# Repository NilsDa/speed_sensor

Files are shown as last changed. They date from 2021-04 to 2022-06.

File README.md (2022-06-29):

# Speed_Sensor

This Repository contains the complete KiCad project of the speed_sensor PCB design as well as important Datasheets and lots of random files and data relating to the project.

## important directories

- **/Datasheets** -> self explanatory
- **/KiCad** -> complete KiCad project and resulting gerber files for pcb printing.
- /Software -> miscellaneous software created mainly to experiment with certain things. not critical
- rest: unsorted files and folders containing parts-lists/footprints/... (need to be properly sorted)

## possibilities for simplifying the design

- maybe ditch the rechargeable lithium battery and use a small coin battery (CR2032) instead... majorly simplifies the PCB design and reduces friction points... But, rechargeable would be nice... Just something to think about.

## LICENSE

No license because project is properly unfinished :D Whoever would want access, needs to contact me.

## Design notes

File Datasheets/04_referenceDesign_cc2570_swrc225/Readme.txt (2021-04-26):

XXXXXXXXXXXXXXXXXXXXXXXXXXXXXXXXXXXXXXXXXXXXXXXXXXXXXXXXXXXXXXXX
X   	Artwork and documentation done by: 					X
X									X
X	TEXAS INSTRUMENTS NORWAY LPW              				X
X  									X
X	Address: Gaustadalléen 21    0349 OSLO                                       		X
X	Phone  : (+47) 22 95 85 44   Fax :  (+47) 22 95 89 05                   		X
X   	web: www.ti.com/lpw                            	 			X
X                                                                           	 			X
XXXXXXXXXXXXXXXXXXXXXXXXXXXXXXXXXXXXXXXXXXXXXXXXXXXXXXXXXXXXXXXX

PCB NAME : CC257X EM discrete	
REVISION: 1.0
DATE: 2010-11-12

PCB DESCRIPTION:4 LAYER PCB 1.6 MM
      Copper        1   35 um
      Dielectric  1-2   0.35 mm (e.g. 2x Prepreg 7628 AT05 47% Resin)
      Copper        2   18 um
      Dielectric  2-3   0.76 mm (4 x 7628M 43% Resin)
      Copper        3   18 um
      Dielectric  3-4   0.35 mm (e.g. 2x Prepreg 7628 AT05 47% Resin)
      Copper        4   35 um

  DE104iML or equivalent substrate (Resin contents around 45%, which gives Er=4.42@2.4GHz, TanD=0.016)
  Dimensions in mil (0.001 inch)
  DOUBLE SIDE SOLDER MASK,
  DOUBLE SIDE SILKSCREEN,
  8 MIL MIN TRACE WIDTH AND 8 MIL MIN ISOLATION.
	
ASSEMBLY: 	LABEL CARD WITH "CC257X_EM_D_R1.0"

FILE: CC257X_EM_Discrete_Reference_Design.ZIP PACKED WITH WinZIP containing 
                 
FILE NAME            				DESCRIPTION                               			FILE TYPE

PCB MANUFACTURING FILES:
L1.SPL               				LAYER 1 COMPONENT SIDE/POSITIVE            		EXT. GERBER
L2.SPL	              			LAYER 2 POSITIVE               		                            EXT. GERBER
L3.SPL               				LAYER 3 POSITIVE            		                            EXT. GERBER
L4.SPL	              			LAYER 4 SOLDER SIDE/POSITIVE               		EXT. GERBER
STOPCOMP.SPL         			SOLDER MASK COMPONENT SIDE/NEGATIVE             	EXT. GERBER
STOPSOLD.SPL         			SOLDER MASK SOLDER SIDE/NEGATIVE                	EXT. GERBER
SILKCOMP.SPL         			SILKSCREEN COMPONENT SIDE/POSITIVE            	EXT. GERBER
SILKSOLD.SPL				SILKSCREEN SOLDER SIDE/POSITIVE			EXT. GERBER
GERBER.REP				DRILL and NC DRILL REPORT				ASCII
DRILL.SPL	            			DRILL/MECHANICAL DRAWING                  		EXT. GERBER
NCDRILL.SPL				NC DRILL THROUGH HOLE                     		EXCELLON			
EXT_GERBER.USR	     			PCB PHOTOPLOTTER DEFINITION FILE			ASCII
CNC.USR		     			NC DRILL DEVICE FILE				ASCII

PCB ASSEMBLY FILES:
CC257X_EM_DISCRETE_PARTLIST.XLS		PART LIST					ASCII
PNP_COMP.REP			              PICK AND PLACE COORDINATES, COMPONENT SIDE	ASCII
PNP_SOLD.REP			              PICK AND PLACE COORDINATES, SOLDER SIDE		ASCII
PASTCOMP.SPL         			SOLDER PASTE COMPONENT SIDE               		EXT. GERBER
PASTSOLD.SPL				SOLDER PASTE SOLDER SIDE			EXT. GERBER
ASSYCOMP.SPL        			ASSEMBLY DRAWING COMPONENT SIDE           		EXT. GERBER
ASSYSOLD.SPL				ASSEMBLY DRAWING SOLDER SIDE			EXT. GERBER

PDF FILES:
CC257X_EM_DISCRETE_SCHEMATIC.PDF	CIRCUIT DIAGRAM
CC257X_EM_DISCRETE_LAYOUT.PDF		LAYOUT DIAGRAM

CADSTAR FILES:
CC257X_EM_DISCRETE.SCM			CADSTAR SCHEMATIC FILE
CC257X_EM_DISCRETE.PCB			CADSTAR LAYOUT FILE

README.TXT           			THIS FILE                                 			ASCII

END.

Release history
--------------------------------------------------------------------------------------------------------------
1.0.0 : Initial release.

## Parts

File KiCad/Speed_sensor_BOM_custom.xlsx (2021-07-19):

Source: | C:\Users\nils_\OneDrive\Documents\Projekte\Speed_sensor\speed_sensor\KiCad\Speed_sensor.sch
Date: | 2021-05-12 22:10
Tool: | Eeschema (5.1.9)-1
Component Count: | 61
Ref | Value | Footprint | Bestückung | Datasheet | Comment | LCSC part no. | hat Manu
AE1 | 2450AT18D0100E_right | myparts:2450AT18D0100E |  | ~ |  |  | ja
C1 | 1u | Capacitor_SMD:C_0603_1608Metric_Pad1.08x0.95mm_HandSolder | 16 | ~ |  | C1592 | nein
C2 | 1u | Capacitor_SMD:C_0603_1608Metric_Pad1.08x0.95mm_HandSolder | 16 | ~ |  | C1592 | nein
C3 | 100n | Capacitor_SMD:C_0402_1005Metric_Pad0.74x0.62mm_HandSolder | 2 | ~ |  | C392963 | ja, aber trotzdem bestellen
C4 | 10u | Capacitor_SMD:C_0603_1608Metric_Pad1.08x0.95mm_HandSolder | 17 | ~ |  | C319196 | nein
C5 | 100n | Capacitor_SMD:C_0402_1005Metric_Pad0.74x0.62mm_HandSolder | 2 | ~ |  | C392963 | ja, aber trotzdem bestellen
C6 | 10u | Capacitor_SMD:C_0603_1608Metric_Pad1.08x0.95mm_HandSolder | 17 | ~ |  | C319196 | nein
C7 | 10u | Capacitor_SMD:C_0603_1608Metric_Pad1.08x0.95mm_HandSolder | 17 | ~ |  | C319196 | nein
C8 | 4.7u | Capacitor_SMD:C_0603_1608Metric_Pad1.08x0.95mm_HandSolder | 18 | ~ |  | C19666 | nein
C9 | 100n | Capacitor_SMD:C_0402_1005Metric_Pad0.74x0.62mm_HandSolder | 2 | ~ |  | C392963 | ja, aber trotzdem bestellen
C10 | 100n | Capacitor_SMD:C_0402_1005Metric_Pad0.74x0.62mm_HandSolder | 2 | ~ |  | C392963 | ja, aber trotzdem bestellen
C11 | 100p | Capacitor_SMD:C_0402_1005Metric_Pad0.74x0.62mm_HandSolder | 3 | ~ |  | C696853 | ja
C12 | N.C. | Capacitor_SMD:C_0402_1005Metric_Pad0.74x0.62mm_HandSolder |  | ~ |  |  | -
C13 | 100n | Capacitor_SMD:C_0402_1005Metric_Pad0.74x0.62mm_HandSolder | 2 | ~ |  | C392963 | ja, aber trotzdem bestellen
C14 | 1u | Capacitor_SMD:C_0603_1608Metric_Pad1.08x0.95mm_HandSolder | 16 | ~ |  | C1592 | nein
C15 | 12p | Capacitor_SMD:C_0402_1005Metric_Pad0.74x0.62mm_HandSolder | 1 | ~ |  | C26406 | nein
C16 | 12p | Capacitor_SMD:C_0402_1005Metric_Pad0.74x0.62mm_HandSolder | 1 | ~ |  | C26406 | nein
C17 | 0,8p | Capacitor_SMD:C_0402_1005Metric_Pad0.74x0.62mm_HandSolder | 4 | ~ |  | C40459 | ja
C18 | 8p | Capacitor_SMD:C_0402_1005Metric_Pad0.74x0.62mm_HandSolder | 5 | ~ |  | C258500 | nein
C19 | 8p | Capacitor_SMD:C_0402_1005Metric_Pad0.74x0.62mm_HandSolder | 5 | ~ |  | C258500 | nein
C20 | 100n | Capacitor_SMD:C_0402_1005Metric_Pad0.74x0.62mm_HandSolder | 2 | ~ |  | C392963 | ja, aber trotzdem bestellen
C21 | 10u | Capacitor_SMD:C_0603_1608Metric_Pad1.08x0.95mm_HandSolder | 17 | ~ |  | C319196 | nein
C22 | N.C. | Capacitor_SMD:C_0402_1005Metric_Pad0.74x0.62mm_HandSolder |  | ~ |  |  | -
D1 | Green (3V) | Diode_SMD:D_0603_1608Metric_Pad1.05x0.95mm_HandSolder |  | ~ |  | C205443 | ja
D2 | IN-GREEN | Diode_SMD:D_0603_1608Metric_Pad1.05x0.95mm_HandSolder |  | ~ |  | C205443 | ja
D3 | charging-ORANGE | Diode_SMD:D_0603_1608Metric_Pad1.05x0.95mm_HandSolder |  | ~ |  | C205445 | ja
D4 | DDZ9678 | Diode_SMD:D_SOD-123 |  | ~ |  | C150464 | ja
D5 | Orange-3V | Diode_SMD:D_0603_1608Metric_Pad1.05x0.95mm_HandSolder |  | ~ |  | C205445 | ja
H1 | VOUT | TestPoint:TestPoint_Pad_D1.5mm |  | ~ |  |  | -
H3 | PGOOD | TestPoint:TestPoint_Pad_D1.5mm |  | ~ |  |  | -
H6 | AIN1 | TestPoint:TestPoint_Pad_D1.5mm |  | ~ |  |  | -
H7 | AIN2 | TestPoint:TestPoint_Pad_D1.5mm |  | ~ |  |  | -
H8 | AIN3 | TestPoint:TestPoint_Pad_D1.5mm |  | ~ |  |  | -
H17 | LiPo+ | TestPoint:TestPoint_Plated_Hole_D2.0mm |  | ~ |  |  | -
H18 | LiPo- | TestPoint:TestPoint_Plated_Hole_D2.0mm |  | ~ |  |  | -
J1 | USB_C_Receptacle_USB2.0 | myparts:USB_C_Receptacle_Palconn_UTC16-G_breitePins |  | https://www.usb.org/sites/default/files/documents/usb_type-c.zip |  | C165948 | nein
J2 | SWD | Connector_PinHeader_1.27mm:PinHeader_2x05_P1.27mm_Vertical_SMD |  | ~
L1 | 2,2u | Inductor_SMD:L_0805_2012Metric_Pad1.15x1.40mm_HandSolder | 22 | ~ |  | C95973 | nein
L2 | 15n | Inductor_SMD:L_0402_1005Metric_Pad0.77x0.64mm_HandSolder | 6 | ~ |  | C329619 | nein
L3 | 10u | Inductor_SMD:L_0603_1608Metric_Pad1.05x0.95mm_HandSolder | 19 | ~ |  | C1035 | nein
L4 | 3,9n | Inductor_SMD:L_0402_1005Metric_Pad0.77x0.64mm_HandSolder | 7 | ~ |  | C90196 | ja
R1 | 470 | Resistor_SMD:R_0402_1005Metric_Pad0.72x0.64mm_HandSolder | 8 | ~ | verwende 510 | C25170 | ja
R2 | 10,8k | Resistor_SMD:R_0603_1608Metric_Pad0.98x0.95mm_HandSolder | 20 | ~ | verwende 10,7k | C22857 | nein
R3 | 10k | Resistor_SMD:R_0603_1608Metric_Pad0.98x0.95mm_HandSolder | 21 | ~ |  | C305012 | ja (nur 20)
R4 | 270 | Resistor_SMD:R_0402_1005Metric_Pad0.72x0.64mm_HandSolder | 9 | ~ |  | C310256 | ja
R5 | 270 | Resistor_SMD:R_0402_1005Metric_Pad0.72x0.64mm_HandSolder | 9 | ~ |  | C310256 | ja
R6 | 27k | Resistor_SMD:R_0402_1005Metric_Pad0.72x0.64mm_HandSolder | 10 | ~ |  | C304599 | ja
R7 | 10k | Resistor_SMD:R_0402_1005Metric_Pad0.72x0.64mm_HandSolder | 11 | ~ |  | C140214 | ja
R8 | 12k | Resistor_SMD:R_0402_1005Metric_Pad0.72x0.64mm_HandSolder | 12 | ~ |  | C25535 | ja
R9 | 470k | Resistor_SMD:R_0402_1005Metric_Pad0.72x0.64mm_HandSolder | 13 | ~ |  | C294637 | ja
R10 | 0 | Resistor_SMD:R_0402_1005Metric_Pad0.72x0.64mm_HandSolder | 14 | ~ |  | C60485 | ja
R11 | 270 | Resistor_SMD:R_0402_1005Metric_Pad0.72x0.64mm_HandSolder | 9 | ~ |  | C310256 | ja
R12 | 1M | Resistor_SMD:R_0402_1005Metric_Pad0.72x0.64mm_HandSolder | 15 | ~ |  | C26087 | ja
U1 | BQ24040DSQR | Package_WSON-10:BQ24040DSQR_breitePins |  |  |  | C81080 | ja
U2 | LMV321 | Package_TO_SOT_SMD:SOT-23-5_HandSoldering |  | http://www.ti.com/lit/ds/symlink/lmv324.pdf |  |  | ja
U3 | ST1PS02 | Package_TQFN-12:ST1PS02CQTR_breitePins |  |  | Free Sample (5x) |  | nein
U4 | nRF52832-QFxx | myparts:QFN-48-1EP_6x6mm_P0.4mm_EP4.6x4.6mm_Handsolder |  | http://infocenter.nordicsemi.com/pdf/nRF52832_PS_v1.4.pdf |  |  | ja
U5 | LIS2DH12 | myparts:LGA-12_2x2mm_P0.5mm_Handsolder |  |  |  | C110926 | ja
U6 | TP1941U | Package_TO_SOT_SMD:SOT-353_SC-70-5_Handsoldering |  |  |  | C248711 | ja
Y1 | 32,768kHz | Crystal:Crystal_SMD_G8-2Pin_3.2x1.5mm |  | ~ |  |  | ja
Y2 | 32MHz | myparts:SMD-2016_4P |  | ~ |  |  | ja

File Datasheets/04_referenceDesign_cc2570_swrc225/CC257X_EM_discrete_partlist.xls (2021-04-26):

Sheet: Partlist TI LPW
CC257X EM discrete 1.0
Mark assembled PCB "CC257X_EM_D_R1.0"
Use with PCB rev 1.0
Ref. | Part name | Pcs/unit | Description | Manufacturer | Part number | Supplier | Ordering code | Alt. Manufacturer | Alt. Part number | Alt. Supplier | Alt. Ordering code | Comments
U1 | CC257X | 1 | 1 Channel or 8 Channel ANT RF Network Processor | TI | CC257x | TI | CC257x
C101;C211;C241;C271;C311 | C_100N_0402_X5R_K_10 | 5 | Capacitor, 100n, 0402, X5R, 10%, 10V | Murata | GRM155R71A104KA01D
C221;C231 | C_12P_0402_NP0_J_50 | 2 | Capacitor, 12p, 0402, NP0, 5%, 50V | Murata | GRM1555C1H120JA01D
C321;C331 | C_15P_0402_NP0_J_50 | 2 | Capacitor, 15p, 0402, NP0, 5%, 50V | Murata | GRM1555C1H150JA01D
C251;C261 | C_18P_0402_NP0_J_50 | 2 | Capacitor, 18p, 0402, NP0, 5% 25V | Murata | GRM1555C1H180JZ01D | ELFA | 65-881-23
C201 | C_1N_0402_NP0_J_50 | 1 | Capacitor, 1n, 0402, NP0, 5%, 50V | Murata | GRM1555C1H102JA01D
C252-253;C262 | C_1P0_0402_NP0_C_50 | 3 | Capacitor, 1p, 0402, NP0, +/-0.25pF 50V | Murata | GRM1555C1H1R0CZ01D
C391;C401 | C_1U_0402_X5R_K_6P3 | 2 | Capacitor, 1u, 0402, X5R, 10%, 6.3V | Murata | GRM155R60J105KE19D
C272 | C_220P_0402_NP0_J_50 | 1 | Capacitor, 220p, 0402, NP0, 5%, 50V | Murata | GRM1555C1H221JA01D
C1 | C_2U2_0402_X5R_M_6P3VDC | 1 | Capacitor, 2u2, 0402, X5R, +/-20%, 6.3V | Murata | GRM155R60J225ME | TTI
C402 | C_2P4_0402_NP0_B_50 | 1 | Capacitor, 2p4, 0402, NP0, +-0.1pF, 50V | Murata | GRM1555C1H2R4BZ01
L252 | L_1N0_0402_S | 1 | Inductor, 1n0, 0402, Monolithic type, +/-0.3 nH | Murata | LQG15HS1N0S02D |  |  | Coilcraft
L251;L261 | L_2N0_0402_S | 2 | Inductor, 2n0, 0402, +/-0.3 nH | Murata | LQG15HS2N0S02D
L253 | L_3N0_0402_S | 1 | Inductor, 3n0, 0402, Monolithic type, +/-0.3 nH | Murata | LQG15HS3N0S02D | ACTE |  | Coilcraft
L1 | L_BEAD_102_0402 | 1 | EMI filter bead, 0402 1k ohms Tape GHz Band Gen Use | Murata | BLM15HG102SN1D | ACTE
R201 | R_2K7_0402_F | 1 | Resistor, 2k7 ohms, 0402, ±1% | Koa | RK73H1ETTP2701F | ELFA | 60-482-50
R301 | R_56K_0402_F | 1 | Resistor, 56k ohms, 0402, ±1% | Koa | RK73H1ETTP5602F | ELFA | 60-488-96
P3 | SMA_SMD | 1 | SMA connector, straight SMD-mount | Hus-Tsan Group Taiwan | SMA-10V21-TGG | EC Partner A/S | SMA-10V21-TGG
P1-2 | SMD_SOCKET_2x10 | 2 | SMD pinrow socket, .050 spacing, 2x10 | Samtec | SFM-110-02-SM-D-A-K-TR | Abacus |  |  |  | AFU, Arrow |  | Yes
X1 | X_32.000/10/20/60/10 | 1 | Crystal, 32.000000MHz, FA-128, 10.0pF, +/-10ppm, (FTC: +/-20ppm at -40/85C), 60ohms | Epson Toyocom | FA-128, 32MHZ, 10PPM, 10PF, 2x1.6mm, -40/+85C, 60ohms | ACTE | Q22FA1280009200
X2 | X_32.768/20/50/40/12 | 1 | Crystal, 32.768 kHz, 12.5pF, 20/50 ppm,SMD package | Epson Toyocom | MC-306 | ACTE | Q13MC3061000314
Total |  | 33

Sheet: Part List CadStar
CC257X | Single chip BLE | 1 | U1
C_100N_0402_X5R_K_10 | Capacitor 0402 | 5 | C101;C211;C241;C271;C311
C_12P_0402_NP0_J_50 | Capacitor 0402 | 2 | C221;C231
C_15P_0402_NP0_J_50 | Capacitor, 0402 | 2 | C321;C331
C_18P_0402_NP0_J_50 | Capacitor 0402 | 2 | C251;C261
C_1N_0402_NP0_J_50 | Capacitor 0402 | 1 | C201
C_1P0_0402_NP0_C_50 | Capacitor 0402 | 3 | C252-253;C262
C_1U_0402_X5R_K_6P3 | Capacitor 0402 | 2 | C391;C401
C_220P_0402_NP0_J_50 | Capacitor 0402 | 1 | C272
C_2U2_0402_X5R_M_4VDC | Capasitor 0402, GRM155R60G225ME15J | 1 | C1
C_2P4_0402_NP0_B_50 | Capacitor 0402 | 1 | C402
FIDUCIAL_MARK_1MM | Fiducial mark, 1mm metal diameter | 6 | FM1-6
L_1N0_0402_S | Inductor 0402 | 1 | L252
L_2N0_0402_S | Inductor 0402 | 2 | L251;L261
L_3N0_0402_S | Inductor 0402 | 1 | L253
L_BEAD_102_0402 | EMI filter bead, BLM15HG102SN1D | 1 | L1
R_2K7_0402_F | Resistor 0402 | 1 | R201
R_56K_0402_F | Resistor 0402 | 1 | R301
SMA_SMD | Surface-mount SMA, straight | 1 | P3
SMD_SOCKET_2x10 | SMD pinrow socket, .050 spacing, SFM-110-02-SM-D-A-K-TR | 2 | P1-2
X_32.000/10/20/60/10 | Epson Toyocom FA128 32 MHz 2x1.6mm 10 pF, -40/85C, Q22FA1280009200 | 1 | X1
X_32.768/20/50/40/12 | Crystal, MC-306 SMD | 1 | X2

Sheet: Parts Not To List
FIDUCIAL_MARK
ANTENNA_IIFA_CC2420
HOLE_4.2
FIDUCIAL_MARK_1MM
HOLE_5

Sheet: Parts Removed
FM1-6 | FIDUCIAL_MARK_1MM | 6 | #N/A | #N/A | #N/A | #N/A | #N/A | #N/A | #N/A | #N/A | #N/A | #N/A

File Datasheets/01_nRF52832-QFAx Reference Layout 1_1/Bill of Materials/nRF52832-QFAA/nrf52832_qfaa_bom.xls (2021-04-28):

Bill of material
PCB: | nRF52832-QFAA Reference Layout
Version: | 1.1
Designator | Value | Description | Footprint Doc
C1, C2, C11, C12, C13, C14 | 12pF | Capacitor, NP0, ±2% | 0402
C3 | 0.8pF | Capacitor, NP0, ±5% | 0402
C4, C5, C8 | 100nF | Capacitor, X7R, ±10% | 0402
C6 | N.C. | Not mounted | 0402
C7 | 100pF | Capacitor, NP0, ±5% | 0402
C9 | 4.7µF | Capacitor, X5R, ±10% | 0603
C10 | 1.0µF | Capacitor, X7R, ±10% | 0603
L1 | 3.9nH | High frequency chip inductor ±5% | 0402
U1 | nRF52832-QFAA | Multi-protocol Bluetooth Low Energy, ANT and 2.4GHz proprietary system-on-chip | QFN-48
X1 | 32MHz | XTAL SMD 2016, 32MHz, Cl=8pF, Total Tol: ±40ppm | XTAL_2016
X2 | 32.768kHz | XTAL SMD 3215, 32.768kHz, Cl=9pF, Total Tol: ±50ppm | XTAL_3215

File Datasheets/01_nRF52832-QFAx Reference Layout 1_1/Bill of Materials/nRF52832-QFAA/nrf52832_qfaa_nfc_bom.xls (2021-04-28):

Bill of material
PCB: | nRF52832-QFAA Reference Layout (NFC)
Version: | 1.1
Designator | Value | Description | Footprint Doc
C1, C2, C11, C12, C13, C14 | 12pF | Capacitor, NP0, ±2% | 0402
C3 | 0.8pF | Capacitor, NP0, ±5% | 0402
C4, C5, C8 | 100nF | Capacitor, X7R, ±10% | 0402
C6 | N.C. | Not mounted | 0402
C7 | 100pF | Capacitor, NP0, ±5% | 0402
C9 | 4.7µF | Capacitor, X5R, ±10% | 0603
C10 | 1.0µF | Capacitor, X7R, ±10% | 0603
C_tune1, C_tune2 | TBD | Capacitor, NP0, ±5% | 0402
L1 | 3.9nH | High frequency chip inductor ±5% | 0402
L2 | 10µH | Chip inductor, IDC,min = 50 mA, ±20% | 0603
L3 | 15nH | High frequency chip inductor ±10% | 0402
U1 | nRF52832-QFAA | Multi-protocol Bluetooth Low Energy, ANT and 2.4GHz proprietary system-on-chip | QFN-48
X1 | 32MHz | XTAL SMD 2016, 32MHz, Cl=8pF, Total Tol: ±40ppm | XTAL_2016
X2 | 32.768kHz | XTAL SMD 3215, 32.768kHz, Cl=9pF, Total Tol: ±50ppm | XTAL_3215

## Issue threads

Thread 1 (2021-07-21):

fix battery protection power off voltage level

NilsDa, 2021-07-21:
- Spannungsteiler an OPV+ Eingang aus 10k und 12k ist: 12k/(12k+10k)=0,5..., sollte aber 0,64... (0,64*Vbatt an OPV+) sein
     - zur Sicherheit nochmal nachrechnen!
     - keine neue Platine nötig! sondern nur update der Widerstände!

NilsDa, 2021-08-24:
Mögliche Anpassung:
12k -> 20k
10k -> 10k
- 12k/(12k+10k) = 1/3 = 0,66... -> damit sollte Spannung auf ausreichendes Level angehoben werden.
- vor Änderung nochmal mit Datenblatt und high/low Spannungen vergleichen.

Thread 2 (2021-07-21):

Thermal Pad connection BQ2404...

NilsDa, 2021-07-21:
- Thermal Pad vom BQ2404... (Battery-management: von 5V-usb IN zu Battery OUT) mit Masse verbinden
     - Neue Revision benötigt
     - Workaround für Rev_1: Mit sehr dünnem Kabel auf Rückseite das Via mit Masse verlöten! (sehr gepfuschter Workaround...)

Closed 2021-07-21.

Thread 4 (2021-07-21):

fix: Gerber File for Backside

NilsDa, 2021-07-21:
Gerber File für Rückseite erstellen lassen (in KiCAD)
- sehr wichtig für neue Rev
- Workaround für Rev_1: Pads auf Rückseite frei kratzen!

Closed 2021-08-07.

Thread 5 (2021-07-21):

Update LED's

NilsDa, 2021-07-21:
- verwende höhere Vorwiderstände an LED's (Müssen nicht so Hell sein & ziehen zu viel Strom).
     - Das Thema kann vielleicht ignoriert werden, da alle LED's aus gehen (außer 3V LED) sobald 5V Versorgung abbricht.
- für tatsächlichen Betrieb muss 3V LED natürlich raus. Wegen unnötigem Stromverbrauch.

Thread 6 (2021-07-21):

increase min VIA-size

NilsDa, 2021-07-21:
Minimale verwendete größe der vias anpassen, da die ganz kleinen vias das Drucken bei JLCPCB teurer machen.
- genaue benötigte Größe auf JLCPCB.com herausfinden bzw. doppelchecken!

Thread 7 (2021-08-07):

Check BQ24... Footprint

NilsDa, 2021-08-07:
Sicherstellen, dass alle Pinzuordnungen auch zum Datenblatt passen

NilsDa, 2021-08-24:
Footprint stimmt mit Datenblatt überein.
- Größe aller Pads und des Massepads sind ok
- alle Zuordnungen der Pads sind ok

Closed 2021-08-24.

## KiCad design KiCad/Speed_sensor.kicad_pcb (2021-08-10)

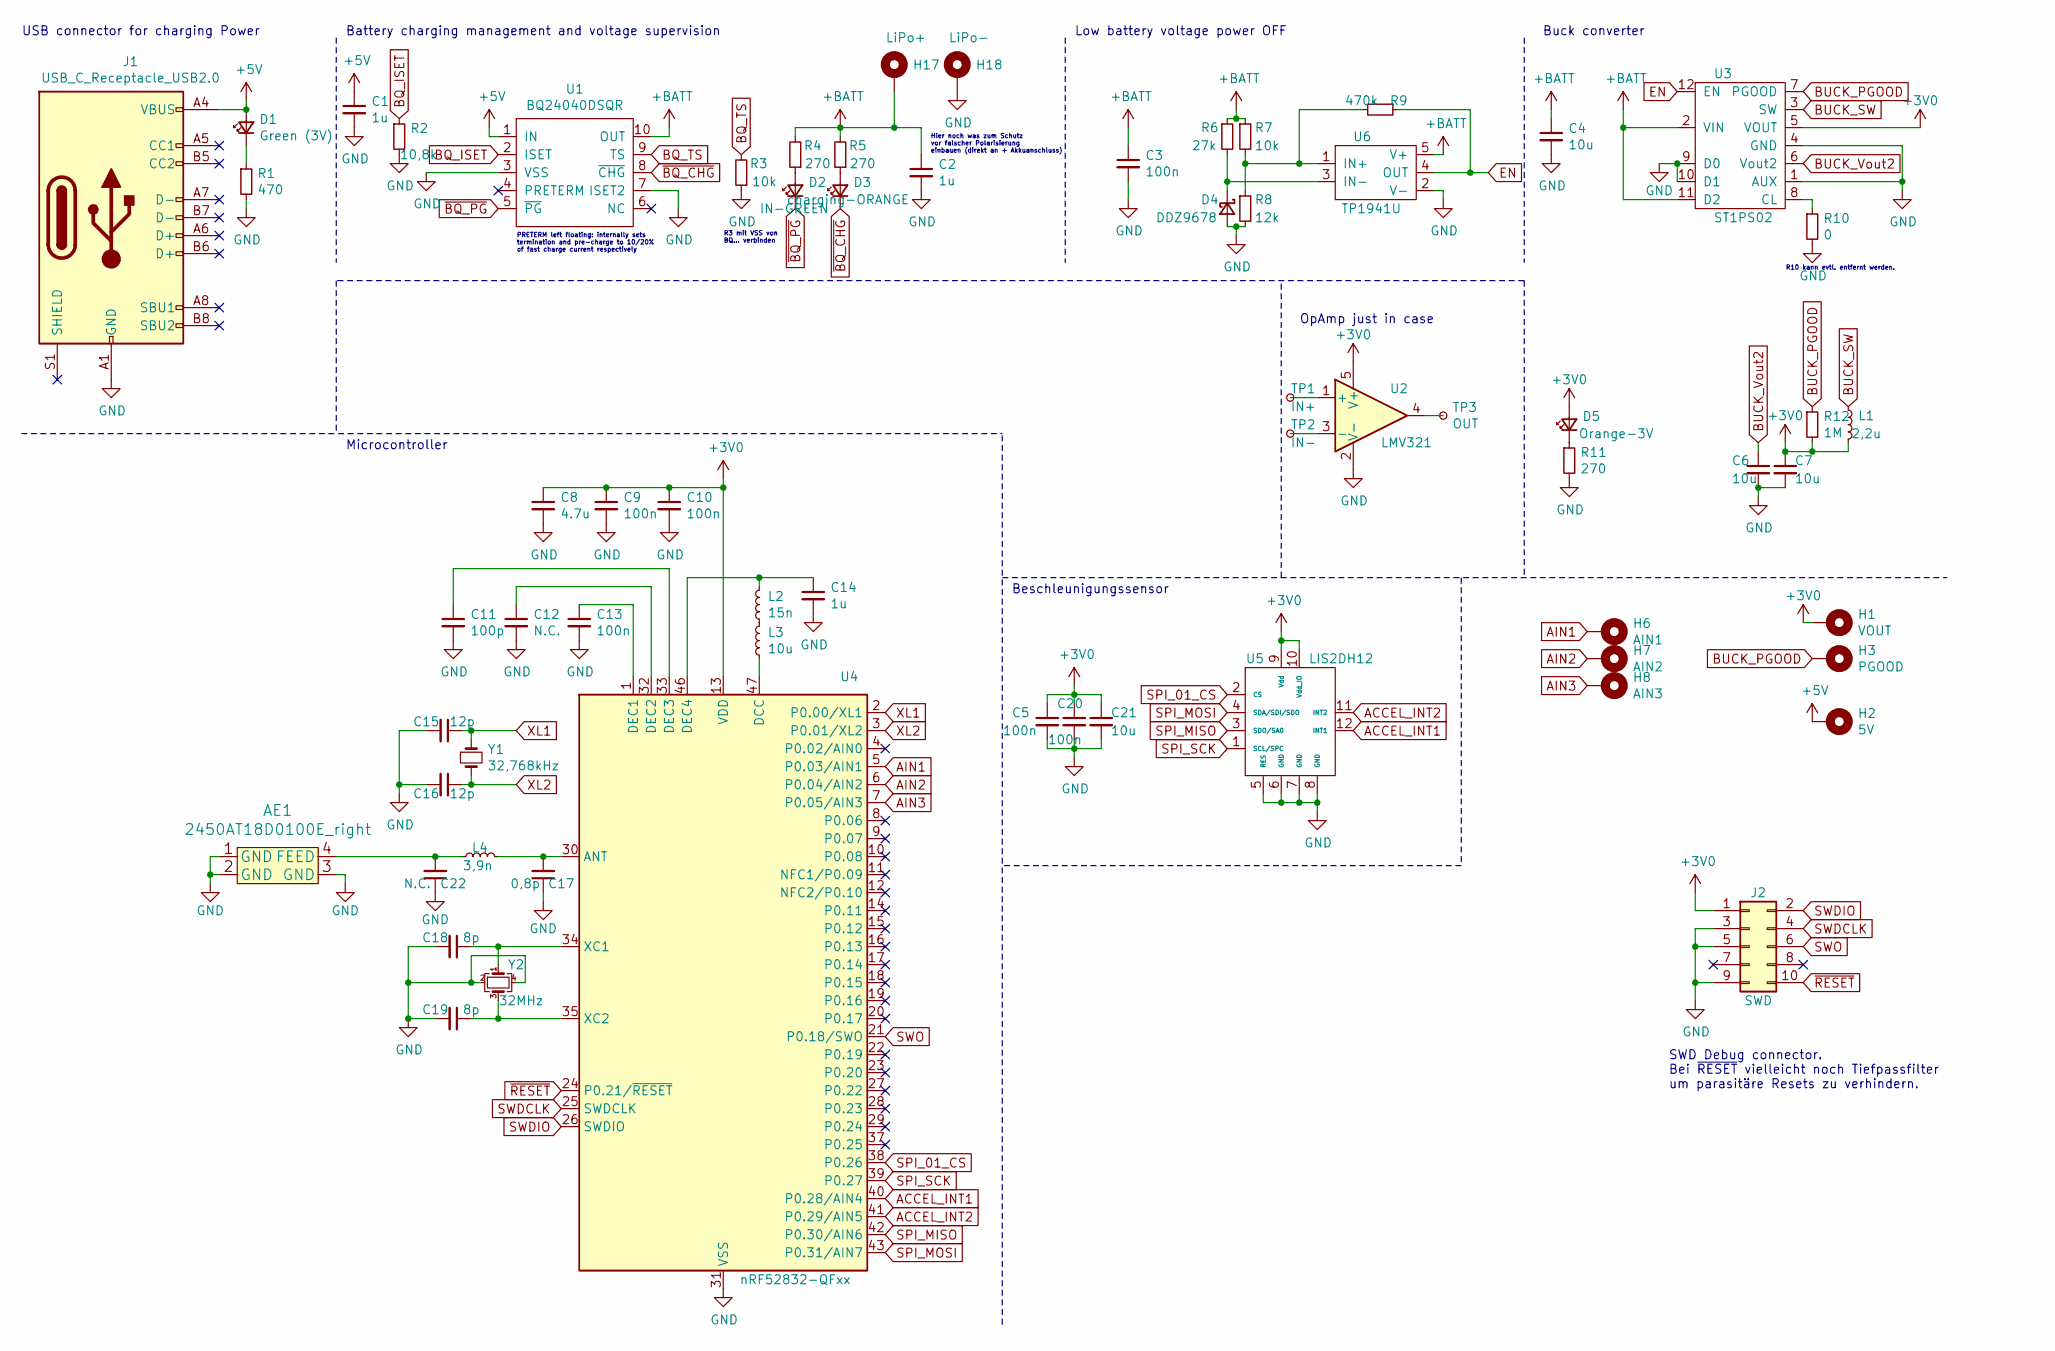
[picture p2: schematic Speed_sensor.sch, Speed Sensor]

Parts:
AE1: 2450AT18D0100E_right; 2450AT18D0100E
C1, C2, C14: 1u; C_0603_1608Metric_Pad1.08x0.95mm_HandSolder
C3, C5, C9, C10, C13, C20: 100n; C_0402_1005Metric_Pad0.74x0.62mm_HandSolder
C4, C6, C7, C21: 10u; C_0603_1608Metric_Pad1.08x0.95mm_HandSolder
C8: 4.7u; C_0603_1608Metric_Pad1.08x0.95mm_HandSolder
C11: 100p; C_0402_1005Metric_Pad0.74x0.62mm_HandSolder
C12, C22: N.C.; C_0402_1005Metric_Pad0.74x0.62mm_HandSolder
C15, C16: 12p; C_0402_1005Metric_Pad0.74x0.62mm_HandSolder
C17: 0,8p; C_0402_1005Metric_Pad0.74x0.62mm_HandSolder
C18, C19: 8p; C_0402_1005Metric_Pad0.74x0.62mm_HandSolder
D1: Green (3V); D_0603_1608Metric_Pad1.05x0.95mm_HandSolder
D2: IN-GREEN; D_0603_1608Metric_Pad1.05x0.95mm_HandSolder
D3: charging-ORANGE; D_0603_1608Metric_Pad1.05x0.95mm_HandSolder
D4: DDZ9678; D_SOD-123
D5: Orange-3V; D_0603_1608Metric_Pad1.05x0.95mm_HandSolder
H1: VOUT; TestPoint_Pad_D1.5mm
H2: 5V; TestPoint_Pad_D1.5mm
H3: PGOOD; TestPoint_Pad_D1.5mm
H6: AIN1; TestPoint_Pad_D1.5mm
H7: AIN2; TestPoint_Pad_D1.5mm
H8: AIN3; TestPoint_Pad_D1.5mm
H17: LiPo+; TestPoint_Plated_Hole_D2.0mm
H18: LiPo-; TestPoint_Plated_Hole_D2.0mm
J1: USB_C_Receptacle_USB2.0; USB_C_Receptacle_Palconn_UTC16-G_breitePins
J2: SWD; PinHeader_2x05_P1.27mm_Vertical_SMD
L1: 2,2u; L_0805_2012Metric_Pad1.15x1.40mm_HandSolder
L2: 15n; L_0402_1005Metric_Pad0.77x0.64mm_HandSolder
L3: 10u; L_0603_1608Metric_Pad1.05x0.95mm_HandSolder
L4: 3,9n; L_0402_1005Metric_Pad0.77x0.64mm_HandSolder
R1: 470; R_0402_1005Metric_Pad0.72x0.64mm_HandSolder
R2: 10,8k; R_0603_1608Metric_Pad0.98x0.95mm_HandSolder
R3: 10k; R_0603_1608Metric_Pad0.98x0.95mm_HandSolder
R4, R5, R11: 270; R_0402_1005Metric_Pad0.72x0.64mm_HandSolder
R6: 27k; R_0402_1005Metric_Pad0.72x0.64mm_HandSolder
R7: 10k; R_0402_1005Metric_Pad0.72x0.64mm_HandSolder
R8: 12k; R_0402_1005Metric_Pad0.72x0.64mm_HandSolder
R9: 470k; R_0402_1005Metric_Pad0.72x0.64mm_HandSolder
R10: 0; R_0402_1005Metric_Pad0.72x0.64mm_HandSolder
R12: 1M; R_0402_1005Metric_Pad0.72x0.64mm_HandSolder
TP1: IN+; TestPoint_Pad_D1.5mm
TP2: IN-; TestPoint_Pad_D1.5mm
TP3: OUT; TestPoint_Pad_D1.5mm
U1: BQ24040DSQR; BQ24040DSQR_breitePins
U2: LMV321; SOT-23-5_HandSoldering
U3: ST1PS02; ST1PS02CQTR_breitePins
U4: nRF52832-QFxx; QFN-48-1EP_6x6mm_P0.4mm_EP4.6x4.6mm_Handsolder
U5: LIS2DH12; LGA-12_2x2mm_P0.5mm_Handsolder
U6: TP1941U; SOT-353_SC-70-5_Handsoldering
Y1: 32,768kHz; Crystal_SMD_G8-2Pin_3.2x1.5mm
Y2: 32MHz; SMD-2016_4P

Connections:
+3V0: C5.1, C7.1, C8.1, C9.1, C10.1, C20.1, C21.1, D5.2 (A), H1.1, J2.1, L1.2, R12.2, U2.5 (V+), U3.5 (VOUT), U4.13 (VDD), U4.36 (VDD), U4.48 (VDD), U5.9 (Vdd), U5.10 (Vdd_IO)
+5V: C1.1, D1.2 (A), H2.1, J1.A4 (VBUS), J1.A9 (VBUS), J1.B4 (VBUS), J1.B9 (VBUS), U1.1 (IN); also elsewhere on the board
+BATT: C2.1, C3.1, C4.1, H17.1, R4.2, R5.2, R6.1, R7.1, U1.10 (OUT), U3.2 (VIN), U3.11 (D2), U6.5 (V+)
ACCEL_INT1: U4.40 (P0.28/AIN4), U5.12 (INT1)
ACCEL_INT2: U4.41 (P0.29/AIN5), U5.11 (INT2)
AIN1: H6.1, U4.5 (P0.03/AIN1)
AIN2: H7.1, U4.6 (P0.04/AIN2)
AIN3: H8.1, U4.7 (P0.05/AIN3)
BQ_ISET: R2.1, U1.2 (ISET)
BQ_TS: R3.2, U1.9 (TS)
BUCK_PGOOD: H3.1, R12.1, U3.7 (PGOOD)
BUCK_SW: L1.1, U3.3 (SW)
BUCK_Vout2: C6.1, U3.6 (Vout2)
EN: R9.1, U3.12 (EN), U6.4 (OUT)
GND: AE1.1 (GND), AE1.2 (GND), AE1.3 (GND), C1.2, C2.2, C3.2, C4.2, C5.2, C6.2, C7.2, C8.2, C9.2, C10.2, C11.2, C12.2, C13.2, C14.2, C15.2, C16.2, C17.1, C18.2, C19.2, C20.2, C21.2, C22.1, D4.2 (A), H18.1, J1.A1 (GND), J1.A12 (GND), J1.B1 (GND), J1.B12 (GND), J2.3, J2.5, J2.9, R1.2, R2.2, R3.1, R8.2, R10.2, R11.2, U1.3 (VSS), U1.7 (ISET2), U2.2 (V-), U3.1 (AUX), U3.4 (GND), U3.9 (D0), U3.10 (D1), U4.31 (VSS), U4.45 (VSS), U4.49 (VSS), U5.5 (RES), U5.6 (GND), U5.7 (GND), U5.8 (GND), U6.2 (V-), Y2.2, Y2.4
unnamed: AE1.4 (FEED), C22.2, L4.1
unnamed: C11.1, U4.33 (DEC3)
unnamed: C12.1, U4.32 (DEC2)
unnamed: C13.1, U4.1 (DEC1)
unnamed: C14.1, L2.2, U4.46 (DEC4)
unnamed: C17.2, L4.2, U4.30 (ANT)
unnamed: C18.1, U4.34 (XC1), Y2.1
unnamed: C19.1, U4.35 (XC2), Y2.3
unnamed: D1.1 (K), R1.1
unnamed: D2.2 (A), R4.1
unnamed: D3.2 (A), R5.1
unnamed: D4.1 (K), R6.2, U6.3 (IN-)
unnamed: D5.1 (K), R11.1
unnamed: L2.1, L3.2
unnamed: L3.1, U4.47 (DCC)
unnamed: R7.2, R8.1, R9.2, U6.1 (IN+)
unnamed: R10.1, U3.8 (CL)
unnamed: TP1.1, U2.1 (+)
unnamed: TP2.1, U2.3 (-)
unnamed: TP3.1, U2.4
SPI_01_CS: U4.38 (P0.26), U5.2 (CS)
SPI_MISO: U4.42 (P0.30/AIN6), U5.3 (SDO/SA0)
SPI_MOSI: U4.43 (P0.31/AIN7), U5.4 (SDA/SDI/SDO)
SPI_SCK: U4.39 (P0.27), U5.1 (SCL/SPC)
SWDCLK: J2.4, U4.25 (SWDCLK)
SWDIO: J2.2, U4.26 (SWDIO)
SWO: J2.6, U4.21 (P0.18/SWO)
XL1: C15.1, U4.2 (P0.00/XL1), Y1.1
XL2: C16.1, U4.3 (P0.01/XL2), Y1.2
~BQ_CHG~: D3.1 (K), U1.8 (~CHG~)
~BQ_PG~: D2.1 (K), U1.5 (~PG~)
~RESET~: J2.10, U4.24 (P0.21/~RESET)

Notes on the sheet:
Microcontroller
Beschleunigungssensor
SWD Debug connector. Bei ~RESET~ vielleicht noch Tiefpassfilter um parasitäre Resets zu verhindern.
USB connector for charging Power
Battery charging management and voltage supervision
Hier noch was zum Schutz vor falscher Polarisierung einbauen (direkt an + Akkuanschluss)
Low battery voltage power OFF
Buck converter
PRETERM left floating: internally sets termination and pre-charge to 10/20% of fast charge current respectively
R10 kann evtl. entfernt werden.
R3 mit VSS von BQ... verbinden
OpAmp just in case

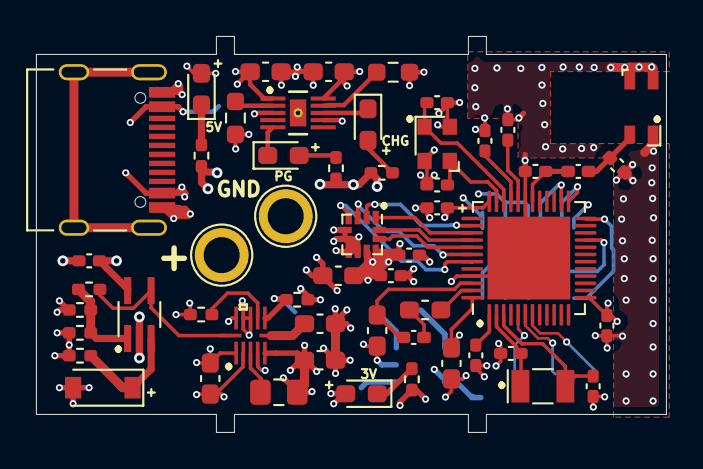
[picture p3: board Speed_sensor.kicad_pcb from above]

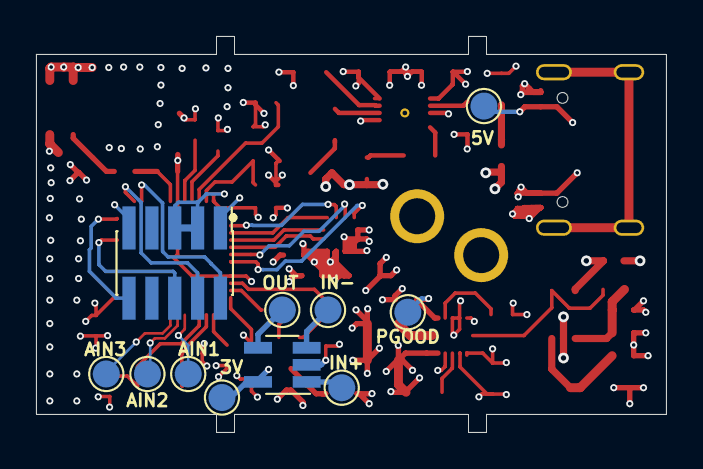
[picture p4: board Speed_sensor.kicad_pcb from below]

Board: 4 copper layers, 35.0 x 22.0 mm, 65 parts (11 on the bottom side), 47 nets.

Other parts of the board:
5V: 5V; TestPoint_Pad_D1.5mm

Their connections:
+5V: 5V.1; also elsewhere on the board

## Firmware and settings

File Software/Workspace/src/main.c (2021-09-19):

#include <stdint.h>
#include <stdbool.h>
#include <string.h>
#include "boards.h"
#include "app_util_platform.h"
#include "nrf_drv_spi.h"
//#include "nrf_spi.h"
#include "nrf_delay.h"
#include "nrf_gpio.h"
#include "nrf_fprintf.h"
#include "nrf_log.h"
#include "nrf_log_ctrl.h"
#include "nrf_log_default_backends.h"
#include "apply_old_config.h"
#include "nrf52832_peripherals.h"
#include "lis2dh12_spi.h"

// SPI defines
#define LIS2DH12_SPI_INSTANCE 0      // LIS2DH12 SPI instance index

#define SPI_PIN_SS_LIS2DH12 26
#define SPI_PIN_MISO 30
#define SPI_PIN_MOSI 31
#define SPI_PIN_SCK 27




// create spi instance
static const nrf_drv_spi_t m_spi = NRF_DRV_SPI_INSTANCE(LIS2DH12_SPI_INSTANCE);
// nrf_drv_spi_t const * const p_m_spi = &m_spi;


void speed_sensor_init()
{
    nrf_drv_spi_config_t spi_config = NRF_DRV_SPI_DEFAULT_CONFIG;       // set default spi config
    
    spi_config.ss_pin = SPI_PIN_SS_LIS2DH12;
    spi_config.miso_pin = SPI_PIN_MISO;
    spi_config.mosi_pin = SPI_PIN_MOSI;
    spi_config.sck_pin = SPI_PIN_SCK;
    spi_config.frequency    = NRF_DRV_SPI_FREQ_4M;
    spi_config.mode     = NRF_DRV_SPI_MODE_3;
    
    LIS2DH12_spi_init(&m_spi, spi_config);

}



int main(void)
{

    speed_sensor_init();


    /* GPIO init */
    uint32_t indPadAIN_1 = 3; // freies Pad auf Rückseite (AIN01) gehört zu GPIO Pin3
    nrf_gpio_cfg_output(indPadAIN_1);
    uint32_t indPadAIN_3 = 5;        /* freies Pad auf Rückseite (AIN03) gehört zu GPIO Pin5 */
    nrf_gpio_cfg_output(indPadAIN_3);


    int intRegValue;    // init variable to safe the register value into

    APP_ERROR_CHECK(NRF_LOG_INIT(NULL));
    NRF_LOG_DEFAULT_BACKENDS_INIT();


    NRF_LOG_INFO("SPI Application started");

    intRegValue = LIS2DH12_read_reg(&m_spi, LIS2DH12_REG_WHO_AM_I);


    if (intRegValue == LIS2DH12_REG_WHO_AM_I_DEFAULT_VALUE)
    {
        NRF_LOG_INFO("The WHO_AM_I value is correct for lis2dh12.");
    }
    else
    {
        NRF_LOG_INFO("The WHO_AM_I value could not be read properly or has the wrong value for lis2dh12.");
    }



    while(1)
    {
        if (intRegValue == LIS2DH12_REG_WHO_AM_I_DEFAULT_VALUE)
        {
            NRF_LOG_INFO("The WHO_AM_I value is correct for lis2dh12.");
            // nrf_gpio_pin_toggle(indPadAIN_3);
            nrf_gpio_pin_toggle(indPadAIN_3);
            nrf_delay_ms(3000);
        }
        else
        {
            NRF_LOG_INFO("The WHO_AM_I value could not be read properly or has the wrong value for lis2dh12.");
            // nrf_gpio_pin_toggle(indPadAIN_3);
            nrf_gpio_pin_toggle(indPadAIN_3);
            nrf_delay_ms(1000);
        }

    }
    return 0;
}

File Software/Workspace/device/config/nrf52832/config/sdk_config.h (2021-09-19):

/**
 * Copyright (c) 2017 - 2020, Nordic Semiconductor ASA
 *
 * All rights reserved.
 *
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
 * 3. Neither the name of Nordic Semiconductor ASA nor the names of its
 *    contributors may be used to endorse or promote products derived from this
 *    software without specific prior written permission.
 *
 * 4. This software, with or without modification, must only be used with a
 *    Nordic Semiconductor ASA integrated circuit.
 *
 * 5. Any software provided in binary form under this license must not be reverse
 *    engineered, decompiled, modified and/or disassembled.
 *
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
 */



#ifndef SDK_CONFIG_H
#define SDK_CONFIG_H
// <<< Use Configuration Wizard in Context Menu >>>\n
#ifdef USE_APP_CONFIG
#include "app_config.h"
#endif
// <h> Application 

//==========================================================
// <o> ANT_NETWORK_NUM - Network number. 
#ifndef ANT_NETWORK_NUM
#define ANT_NETWORK_NUM 0
#endif

// <o> BROADCAST_CHANNEL_NUMBER - Broadcast channel number. 
#ifndef BROADCAST_CHANNEL_NUMBER
#define BROADCAST_CHANNEL_NUMBER 0
#endif

// <o> CHAN_ID_DEV_NUM - Channel ID: Device Number. 
#ifndef CHAN_ID_DEV_NUM
#define CHAN_ID_DEV_NUM 2
#endif

// <o> CHAN_ID_DEV_TYPE - Channel ID: Device Type. 
#ifndef CHAN_ID_DEV_TYPE
#define CHAN_ID_DEV_TYPE 2
#endif

// <o> CHAN_ID_TRANS_TYPE - Channel ID: Transmission type. 
#ifndef CHAN_ID_TRANS_TYPE
#define CHAN_ID_TRANS_TYPE 1
#endif

// <o> CHAN_PERIOD - Channel Period (in 32 kHz counts). 
#ifndef CHAN_PERIOD
#define CHAN_PERIOD 8192
#endif

// <o> RF_FREQ - RF Frequency. 
#ifndef RF_FREQ
#define RF_FREQ 66
#endif

// </h> 
//==========================================================

// <h> nRF_ANT 

//==========================================================
// <q> ANT_CHANNEL_CONFIG_ENABLED  - ant_channel_config - ANT common channel configuration
 

#ifndef ANT_CHANNEL_CONFIG_ENABLED
#define ANT_CHANNEL_CONFIG_ENABLED 1
#endif

// </h> 
//==========================================================

// <h> nRF_Drivers 

//==========================================================
// <e> GPIOTE_ENABLED - nrf_drv_gpiote - GPIOTE peripheral driver - legacy layer
//==========================================================
#ifndef GPIOTE_ENABLED
#define GPIOTE_ENABLED 1
#endif
// <o> GPIOTE_CONFIG_NUM_OF_LOW_POWER_EVENTS - Number of lower power input pins 
#ifndef GPIOTE_CONFIG_NUM_OF_LOW_POWER_EVENTS
#define GPIOTE_CONFIG_NUM_OF_LOW_POWER_EVENTS 4
#endif

// <o> GPIOTE_CONFIG_IRQ_PRIORITY  - Interrupt priority
 

// <i> Priorities 0,2 (nRF51) and 0,1,4,5 (nRF52) are reserved for SoftDevice
// <0=> 0 (highest) 
// <1=> 1 
// <2=> 2 
// <3=> 3 
// <4=> 4 
// <5=> 5 
// <6=> 6 
// <7=> 7 

#ifndef GPIOTE_CONFIG_IRQ_PRIORITY
#define GPIOTE_CONFIG_IRQ_PRIORITY 6
#endif

// </e>

// <e> NRFX_GPIOTE_ENABLED - nrfx_gpiote - GPIOTE peripheral driver
//==========================================================
#ifndef NRFX_GPIOTE_ENABLED
#define NRFX_GPIOTE_ENABLED 1
#endif
// <o> NRFX_GPIOTE_CONFIG_NUM_OF_LOW_POWER_EVENTS - Number of lower power input pins 
#ifndef NRFX_GPIOTE_CONFIG_NUM_OF_LOW_POWER_EVENTS
#define NRFX_GPIOTE_CONFIG_NUM_OF_LOW_POWER_EVENTS 1
#endif

// <o> NRFX_GPIOTE_CONFIG_IRQ_PRIORITY  - Interrupt priority
 
// <0=> 0 (highest) 
// <1=> 1 
// <2=> 2 
// <3=> 3 
// <4=> 4 
// <5=> 5 
// <6=> 6 
// <7=> 7 

#ifndef NRFX_GPIOTE_CONFIG_IRQ_PRIORITY
#define NRFX_GPIOTE_CONFIG_IRQ_PRIORITY 6
#endif

// <e> NRFX_GPIOTE_CONFIG_LOG_ENABLED - Enables logging in the module.
//==========================================================
#ifndef NRFX_GPIOTE_CONFIG_LOG_ENABLED
#define NRFX_GPIOTE_CONFIG_LOG_ENABLED 0
#endif
// <o> NRFX_GPIOTE_CONFIG_LOG_LEVEL  - Default Severity level
 
// <0=> Off 
// <1=> Error 
// <2=> Warning 
// <3=> Info 
// <4=> Debug 

#ifndef NRFX_GPIOTE_CONFIG_LOG_LEVEL
#define NRFX_GPIOTE_CONFIG_LOG_LEVEL 3
#endif

// <o> NRFX_GPIOTE_CONFIG_INFO_COLOR  - ANSI escape code prefix.
 
// <0=> Default 
// <1=> Black 
// <2=> Red 
// <3=> Green 
// <4=> Yellow 
// <5=> Blue 
// <6=> Magenta 
// <7=> Cyan 
// <8=> White 

#ifndef NRFX_GPIOTE_CONFIG_INFO_COLOR
#define NRFX_GPIOTE_CONFIG_INFO_COLOR 0
#endif

// <o> NRFX_GPIOTE_CONFIG_DEBUG_COLOR  - ANSI escape code prefix.
 
// <0=> Default 
// <1=> Black 
// <2=> Red 
// <3=> Green 
// <4=> Yellow 
// <5=> Blue 
// <6=> Magenta 
// <7=> Cyan 
// <8=> White 

#ifndef NRFX_GPIOTE_CONFIG_DEBUG_COLOR
#define NRFX_GPIOTE_CONFIG_DEBUG_COLOR 0
#endif

// </e>

// </e>

// <e> NRFX_PRS_ENABLED - nrfx_prs - Peripheral Resource Sharing module
//==========================================================
#ifndef NRFX_PRS_ENABLED
#define NRFX_PRS_ENABLED 1
#endif
// <q> NRFX_PRS_BOX_0_ENABLED  - Enables box 0 in the module.
 

#ifndef NRFX_PRS_BOX_0_ENABLED
#define NRFX_PRS_BOX_0_ENABLED 0
#endif

// <q> NRFX_PRS_BOX_1_ENABLED  - Enables box 1 in the module.
 

#ifndef NRFX_PRS_BOX_1_ENABLED
#define NRFX_PRS_BOX_1_ENABLED 0
#endif

// <q> NRFX_PRS_BOX_2_ENABLED  - Enables box 2 in the module.
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

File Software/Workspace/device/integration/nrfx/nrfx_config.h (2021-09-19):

/**
 * Copyright (c) 2017 - 2020, Nordic Semiconductor ASA
 *
 * All rights reserved.
 *
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
 * 3. Neither the name of Nordic Semiconductor ASA nor the names of its
 *    contributors may be used to endorse or promote products derived from this
 *    software without specific prior written permission.
 *
 * 4. This software, with or without modification, must only be used with a
 *    Nordic Semiconductor ASA integrated circuit.
 *
 * 5. Any software provided in binary form under this license must not be reverse
 *    engineered, decompiled, modified and/or disassembled.
 *
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
 */

#ifndef NRFX_CONFIG_H__
#define NRFX_CONFIG_H__

// TODO - temporary redirection
#include <sdk_config.h>




// <<< Use Configuration Wizard in Context Menu >>>\n

// <h> nRF_Drivers

// <e> NRFX_CLOCK_ENABLED - nrfx_clock - CLOCK peripheral driver
//==========================================================
#ifndef NRFX_CLOCK_ENABLED
#define NRFX_CLOCK_ENABLED 1
#endif
// <o> NRFX_CLOCK_CONFIG_LF_SRC  - LF Clock Source

// <0=> RC
// <1=> XTAL
// <2=> Synth
// <131073=> External Low Swing
// <196609=> External Full Swing

#ifndef NRFX_CLOCK_CONFIG_LF_SRC
#define NRFX_CLOCK_CONFIG_LF_SRC 1
#endif

// <q> NRFX_CLOCK_CONFIG_LF_CAL_ENABLED  - Enables LF Clock Calibration Support

#ifndef NRFX_CLOCK_CONFIG_LF_CAL_ENABLED
#define NRFX_CLOCK_CONFIG_LF_CAL_ENABLED 0
#endif

// <o> NRFX_CLOCK_CONFIG_IRQ_PRIORITY  - Interrupt priority

// <0=> 0 (highest)
// <1=> 1
// <2=> 2
// <3=> 3
// <4=> 4
// <5=> 5
// <6=> 6
// <7=> 7

#ifndef NRFX_CLOCK_CONFIG_IRQ_PRIORITY
#define NRFX_CLOCK_CONFIG_IRQ_PRIORITY 7
#endif

// <e> NRFX_CLOCK_CONFIG_LOG_ENABLED - Enables logging in the module.
//==========================================================
#ifndef NRFX_CLOCK_CONFIG_LOG_ENABLED
#define NRFX_CLOCK_CONFIG_LOG_ENABLED 0
#endif
// <o> NRFX_CLOCK_CONFIG_LOG_LEVEL  - Default Severity level

// <0=> Off
// <1=> Error
// <2=> Warning
// <3=> Info
// <4=> Debug

#ifndef NRFX_CLOCK_CONFIG_LOG_LEVEL
#define NRFX_CLOCK_CONFIG_LOG_LEVEL 3
#endif

// <o> NRFX_CLOCK_CONFIG_INFO_COLOR  - ANSI escape code prefix.

// <0=> Default
// <1=> Black
// <2=> Red
// <3=> Green
// <4=> Yellow
// <5=> Blue
// <6=> Magenta
// <7=> Cyan
// <8=> White

#ifndef NRFX_CLOCK_CONFIG_INFO_COLOR
#define NRFX_CLOCK_CONFIG_INFO_COLOR 0
#endif

// <o> NRFX_CLOCK_CONFIG_DEBUG_COLOR  - ANSI escape code prefix.

// <0=> Default
// <1=> Black
// <2=> Red
// <3=> Green
// <4=> Yellow
// <5=> Blue
// <6=> Magenta
// <7=> Cyan
// <8=> White

#ifndef NRFX_CLOCK_CONFIG_DEBUG_COLOR
#define NRFX_CLOCK_CONFIG_DEBUG_COLOR 0
#endif

// </e>

// </e>

// <e> NRFX_COMP_ENABLED - nrfx_comp - COMP peripheral driver
//==========================================================
#ifndef NRFX_COMP_ENABLED
#define NRFX_COMP_ENABLED 1
#endif
// <o> NRFX_COMP_CONFIG_REF  - Reference voltage

// <0=> Internal 1.2V
// <1=> Internal 1.8V
// <2=> Internal 2.4V
// <4=> VDD
// <7=> ARef

#ifndef NRFX_COMP_CONFIG_REF
#define NRFX_COMP_CONFIG_REF 1
#endif

// <o> NRFX_COMP_CONFIG_MAIN_MODE  - Main mode

// <0=> Single ended
// <1=> Differential

#ifndef NRFX_COMP_CONFIG_MAIN_MODE
#define NRFX_COMP_CONFIG_MAIN_MODE 0
#endif

// <o> NRFX_COMP_CONFIG_SPEED_MODE  - Speed mode

// <0=> Low power
// <1=> Normal
// <2=> High speed

#ifndef NRFX_COMP_CONFIG_SPEED_MODE
#define NRFX_COMP_CONFIG_SPEED_MODE 2
#endif

// <o> NRFX_COMP_CONFIG_HYST  - Hystheresis

// <0=> No
// <1=> 50mV

#ifndef NRFX_COMP_CONFIG_HYST
#define NRFX_COMP_CONFIG_HYST 0
#endif

// <o> NRFX_COMP_CONFIG_ISOURCE  - Current Source

// <0=> Off
// <1=> 2.5 uA
// <2=> 5 uA
// <3=> 10 uA

#ifndef NRFX_COMP_CONFIG_ISOURCE
#define NRFX_COMP_CONFIG_ISOURCE 0
#endif

// <o> NRFX_COMP_CONFIG_INPUT  - Analog input

// <0=> 0
// <1=> 1
// <2=> 2
// <3=> 3
// <4=> 4
// <5=> 5
// <6=> 6
// <7=> 7

#ifndef NRFX_COMP_CONFIG_INPUT
#define NRFX_COMP_CONFIG_INPUT 0
#endif

// <o> NRFX_COMP_CONFIG_IRQ_PRIORITY  - Interrupt priority

// <0=> 0 (highest)
// <1=> 1
// <2=> 2
// <3=> 3
// <4=> 4
// <5=> 5
// <6=> 6
// <7=> 7

#ifndef NRFX_COMP_CONFIG_IRQ_PRIORITY
#define NRFX_COMP_CONFIG_IRQ_PRIORITY 7
#endif

// <e> NRFX_COMP_CONFIG_LOG_ENABLED - Enables logging in the module.
//==========================================================
#ifndef NRFX_COMP_CONFIG_LOG_ENABLED
#define NRFX_COMP_CONFIG_LOG_ENABLED 0
#endif
// <o> NRFX_COMP_CONFIG_LOG_LEVEL  - Default Severity level

// <0=> Off
// <1=> Error
// <2=> Warning
// <3=> Info
// <4=> Debug

#ifndef NRFX_COMP_CONFIG_LOG_LEVEL
#define NRFX_COMP_CONFIG_LOG_LEVEL 3
#endif

// <o> NRFX_COMP_CONFIG_INFO_COLOR  - ANSI escape code prefix.

// <0=> Default
// <1=> Black
// <2=> Red
// <3=> Green
// <4=> Yellow
// <5=> Blue
// <6=> Magenta
// <7=> Cyan
// <8=> White

#ifndef NRFX_COMP_CONFIG_INFO_COLOR
#define NRFX_COMP_CONFIG_INFO_COLOR 0
#endif

// <o> NRFX_COMP_CONFIG_DEBUG_COLOR  - ANSI escape code prefix.
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

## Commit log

2021-04-26 all initial KiCad files (only schematics started)
    [Speed_sensor.kicad_pcb, Speed_sensor.sch]
2021-04-26 hierarchische Aufteilung der Schematic angefangen & power circuit um Battery management + usb connector erweitert
    [Speed_sensor.sch, ant_module.sch, power_circuit.sch]
2021-04-26 Schematic ein bisschen sortiert
    [Speed_sensor.sch, power_circuit.sch]
2021-04-26 added green LED for when USB is connected to power circuit
    [power_circuit.sch]
2021-04-26 changed SPI labels to make it more general and not specific to the BMA Sensor
    [Speed_sensor.sch]
2021-04-26 added battery voltage supervision version 1
    [power_circuit.sch]
2021-04-26 added files for reference design for cc2570
    [CC257X_EM_discrete_partlist.xls]
2021-04-27 corrected battery voltage supervision
    [power_circuit.sch]
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2021-04-27 int pins am BMA hinzugefügt (aber noch nicht an nrf angeschlossen
    [Speed_sensor.sch]
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2021-04-27 power circuit übersichtlicher gemacht, low battery voltage detection verändert.
    [Speed_sensor.sch]
2021-04-28 updated battery charging with Manus chip, added low frequency crystal
    [Speed_sensor.sch]
2021-04-28 switch to Manus Accelerometer, switch back to A4 page size
    [Speed_sensor.sch]
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2021-04-28 added pads for all AINx, decided on which GPIO to use (wil prop change again)
    [Speed_sensor.sch]
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2021-04-28 added a lot of footprints (mainly crystal and all the chips are missing)
    [Speed_sensor.sch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]
2021-04-30 added all footprints (LFO crystal might have to be updated)
    [Speed_sensor.kicad_pcb, Speed_sensor.sch]
2021-04-30 custom footprints von Manu übernommen (jetzt sollte alles passen), PCB layout angefangen.
    [Speed_sensor.kicad_pcb, Speed_sensor.sch]
2021-04-30 layout update (Bauteile um den nrf grob positioniert)
    [Speed_sensor.kicad_pcb]
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2021-04-30 layout. parts roughly put into the right spot
    [Speed_sensor.kicad_pcb, Speed_sensor.sch]
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2021-05-02 changed some labels in the .sch so all power stuff is labeled correctly
    [Speed_sensor.kicad_pcb, Speed_sensor.sch]
2021-05-02 changed which GPIO pins are used for SPI
    [Speed_sensor.kicad_pcb, Speed_sensor.sch]
2021-05-04 layout part positions changed slightly, added 3,5cm x 2cm outline (as a goal)
    [Speed_sensor.kicad_pcb, Speed_sensor.sch]
2021-05-04 defined PCB size 35mm x 20mm, started rearranging layout (starting with power circuit (5V + Batt low voltage turn OFF)
    [Speed_sensor.kicad_pcb, Speed_sensor.sch]
2021-05-04 added Buck converter part to the properly sized layout
    [Speed_sensor.kicad_pcb]
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2021-05-04 Bauteilplatzierungen leicht angepasst. Bemerkt, dass PCB wahrsch größer werden muss.
    [Speed_sensor.kicad_pcb]
2021-05-05 kleine Änderungen an Bauteilplatzierungen um vias unterbringen zu können, 'keepout area' für Antenne eingefügt.
    [Speed_sensor.kicad_pcb, Speed_sensor.sch]
2021-05-05 Änderungen nach Treffen mit Manu, opamp für alle Fälle, opamp footprint geändert, C footprint in impedance matching circuit hinzugefügt, SWD connector footprint geändert.
    [LCSC_Exported_20210428_030935.csv, LCSC_Exported_20210428_030938.csv, LCSC_Exported_20210428_030939.csv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]
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2021-05-05 buck converter footprint pads verkleinert, nrf + naheliegende bauteile gedreht eingefügt, Antenne neu platziert
    [Speed_sensor.kicad_pcb, Speed_sensor.sch]
2021-05-08 Datasheet für quarz hinzugefügt, kleine änderungen am Layout (nichts nennenswertes)
    [Speed_sensor.kicad_pcb, Speed_sensor.sch]
2021-05-10 power und GND plane aufgeteilt (quarze noch nicht beachtet, Antenne aber schon)
    [Speed_sensor.kicad_pcb]
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2021-05-10 Änderungen am layout: vias, leitungen & pads leicht umplatziert
    [Speed_sensor.kicad_pcb]
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2021-05-12 angefangen die genauen Bauteile zuzuordnen, paar footprints geändert (LED-widerstände von 0603 zu 0402)
    [Speed_sensor.kicad_pcb, Speed_sensor.sch, Speed_sensor_BOM_custom.xlsx]
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2021-05-19 updated footprint L1, BOM erweitert und weitere Teile zugeordnet
    [Speed_sensor.kicad_pcb, Speed_sensor.sch, Speed_sensor_BOM_custom.xlsx]
2021-05-20 im layout paar Bezeichnungen entfernt (die zurück gekommen sind nachdem footprints geändert wurden)
    [Speed_sensor.kicad_pcb, Speed_sensor_BOM_custom.xlsx]
2021-05-21 erste Beschriftungen ins Layout eingefügt (sehr wenig, rückseite kann noch nichts eingefügt werden...)
    [Speed_sensor.kicad_pcb]
2021-05-22 paar Markierungen für + Voltage sowie PIN1 im layout hinzugefügt
    [Speed_sensor.kicad_pcb]
2021-05-29 restliche Bauteile zugeornet und raus gesucht (bei LCSC bereit zum Bestellen); restliche Markierungen im Layout gemacht; 4 Kerben an langen Seiten des PCB hinzugefügt um ggf. PCB in Gehäuse zu drücke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
    [Speed_sensor.kicad_pcb, Speed_sensor.sch, Speed_sensor_BOM_custom.xlsx]
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2021-05-29 design rule check im layout durchgeführt und kleinigkeiten angepasst
    [Speed_sensor.kicad_pcb]
2021-05-29 alle Files zum Bestellen erstellt und Bestellungen bei jlcpcb und lcsc raus geschickt :).
    [Speed_sensor-B_Cu.gbr, Speed_sensor-Edge_Cuts.gbr, Speed_sensor-F_Cu.gbr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]
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2021-06-09 paar Änderungen an der CMakeLists.txt von gestern; Excel der Bestellung vom 01.Juni angepasst (alles angekommen :)))
    [LCSC_Bestellung_01_Juni21.xlsx]
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2021-07-21 added back-SilkS and all Pad-Names + Pin1 marking at SWD footprintgit status
    [Speed_sensor.kicad_pcb]
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
